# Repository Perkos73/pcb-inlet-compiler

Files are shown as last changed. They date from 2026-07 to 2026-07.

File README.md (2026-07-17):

# PCB INLET

Dwuwarstwowa płytka wejściowa zasilania sieciowego dla projektu Custom Step-Down PSU 230 V → 100 V.

## Stan projektu

Rewizja PCB: `PCB1-PCB-01R1`

Główny plik płytki:

`pcb-inlet.kicad_pcb`

Układ elektryczny, geometria płytki i trasowanie nie zostały zmienione. Ujednolicono nazwę pliku, strukturę repozytorium oraz automatyczne testy GitHub Actions.

## Parametry PCB

| Parametr | Wartość |
|---|---:|
| Wymiary | 105 × 70 mm |
| Liczba warstw miedzi | 2 |
| Materiał | FR-4 |
| Grubość laminatu | 1,6 mm |
| Grubość miedzi | 70 µm / 2 oz |
| Montaż elementów | THT |
| Liczba footprintów | 10 |
| Liczba przelotek | 0 |
| Otwory montażowe | 4 × 3,2 mm, NPTH, M3 |

## Funkcje płytki

Płytka zawiera:

- wejście i wyjście sieciowe na złączach śrubowych,
- bezpiecznik topikowy w przewodzie fazowym,
- warystor zabezpieczający,
- kondensator klasy X2,
- rezystor rozładowujący,
- sieci `L_IN`, `L_FUSED` i `N_IN`,
- cztery otwory montażowe M3.

## Struktura repozytorium

Najważniejsze pliki:

- `pcb-inlet.kicad_pcb` — projekt płytki KiCad,
- `.github/workflows/kicad-validate.yml` — automatyczna kontrola DRC,
- `.github/workflows/kicad-manufacturing.yml` — generowanie plików produkcyjnych,
- `.gitignore` — wykluczenie plików generowanych automatycznie,
- `README.md` — opis projektu.

## Automatyczna walidacja

Workflow `kicad-validate.yml` uruchamia się przy Pull Requestach oraz zmianach na głównej gałęzi.

Walidacja:

1. uruchamia KiCad CLI 8.0.9,
2. otwiera plik PCB,
3. wykonuje pełny raport DRC,
4. wykonuje kontrolę błędów blokujących,
5. zapisuje raporty jako artifact GitHub Actions.

Aktualny wynik kontroli bramkującej:

- 0 błędów,
- 0 niepołączonych padów.

Pełny raport może zawierać ostrzeżenia i naruszenia informacyjne wymagające ręcznej oceny.

## Pliki produkcyjne

Workflow `kicad-manufacturing.yml` jest przeznaczony do automatycznego generowania:

- warstw Gerber,
- plików wierceń,
- map wierceń,
- pliku IPC-D-356,
- raportów DRC,
- manifestu plików,
- sum kontrolnych SHA-256.

Pliki produkcyjne nie są zapisywane bezpośrednio w repozytorium. Są udostępniane w GitHub Actions jako artifact do pobrania.

## Zalecane parametry zamówienia PCB

- 2 warstwy,
- wymiary 105 × 70 mm,
- materiał FR-4,
- grubość 1,6 mm,
- miedź 2 oz,
- solder mask po obu stronach,
- opis po obu stronach,
- bez panelizacji,
- bez kontrolowanej impedancji,
- bez V-score,
- bez metalizacji krawędzi,
- bez otworów castellated.

## Bezpieczeństwo

Projekt pracuje z napięciem sieciowym.

Przed wykonaniem i uruchomieniem płytki należy sprawdzić:

- wymagane odstępy izolacyjne,
- parametry napięciowe i prądowe elementów,
- klasę bezpieczeństwa kondensatora,
- właściwy dobór bezpiecznika,
- sposób uziemienia urządzenia,
- zgodność konstrukcji z obowiązującymi wymaganiami bezpieczeństwa.

Uruchamianie układu powinno odbywać się wyłącznie przez osobę posiadającą odpowiednie doświadczenie z urządzeniami sieciowymi.

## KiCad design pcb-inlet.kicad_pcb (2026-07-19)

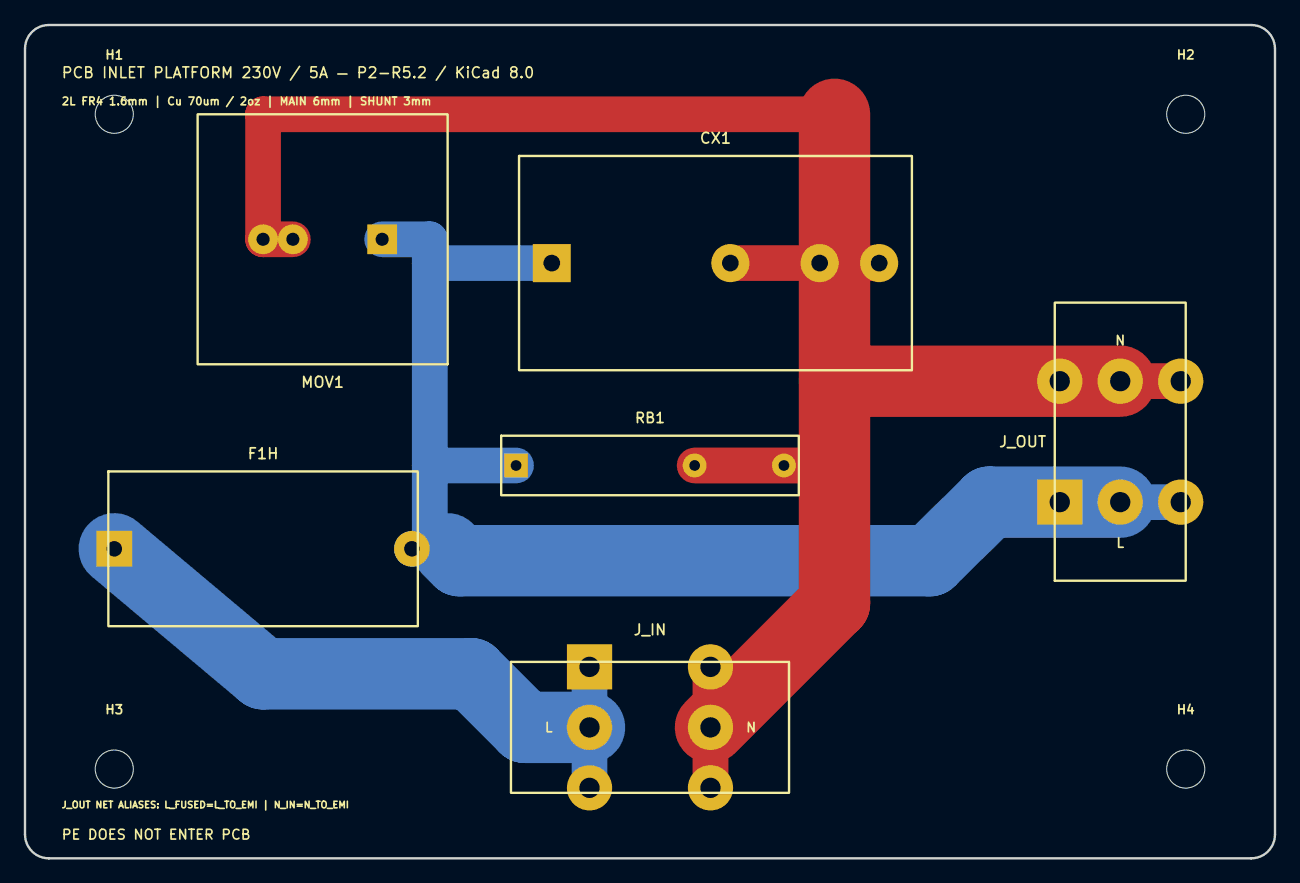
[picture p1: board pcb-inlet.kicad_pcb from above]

Board: 2 copper layers, 105.0 x 70.0 mm, 10 parts (0 on the bottom side), 3 nets.

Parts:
CX1: Iskra KNB1532 0.22uF X2 / fitted P22.5; CX_X2_P15_P22.5_P27.5
F1H: Schurter OGN 0031.8211 / F1 T500mA; Schurter_OGN_0031.8211
H1, H2, H3, H4: NPTH 3.2 / 6mm mains clearance; MountingHole_3.2mm_M3
J_IN: Phoenix 1998784 PCV + plug 1913507; Phoenix_1998784_PCV_2P_P10.16
J_OUT: Phoenix 1998784 PCV + plug 1913507; Phoenix_1998784_PCV_2P_P10.16
MOV1: S14K320 fitted / S20 option; MOV_S14_S20_P7.5_P10
RB1: VR37 680k / fitted P15; VR37_P15_P22.5

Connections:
L_FUSED: CX1.1, F1H.2, J_OUT.1, MOV1.1, RB1.1
L_IN: F1H.1, J_IN.1
N_IN: CX1.2, J_IN.2, J_OUT.2, MOV1.2, RB1.2

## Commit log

2026-07-13 Automatyczny zapis Gerberów [skip ci]
    [pcb_inlet-B_Courtyard.gbr, pcb_inlet-B_Fab.gbr, pcb_inlet-B_Mask.gbs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]
2026-07-16 Update README to match pcb-psu-led standard
2026-07-16 Add KiCad validation and manufacturing workflows
2026-07-16 Rename PCB file for consistent naming
    [pcb-inlet.kicad_pcb]
2026-07-16 Remove obsolete generated Gerber files
    [pcb_inlet-B_Courtyard.gbr, pcb_inlet-B_Fab.gbr, pcb_inlet-B_Mask.gbs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]
2026-07-16 Remove obsolete Gerber workflow
2026-07-17 Use KiCad 8 for PCB validation
2026-07-17 Pass PCB filename into validation container
2026-07-17 Remove unsupported KiCad 8 render commands
2026-07-17 Use KiCad 8 for manufacturing workflow
2026-07-17 Migrate project and workflows to KiCad 10.0.4
    [pcb-inlet.kicad_pcb]
2026-07-19 pcb: set rev P2-R4.1, Lead-Free HASL and add L/N silk
    - title block revision: PCB-INLET_P2-R4.1
    - surface finish: Lead-Free HASL
    - L/N silkscreen labels for J_IN and J_OUT
    - no changes to copper, routing, pads, holes, outline, placement, nets or courtyard
    [pcb-inlet.kicad_pcb]
2026-07-19 set REVISION to PCB-INLET_P2-R4.1g.yml
    Align production folder, MANIFEST, ZIP and artifact name with the board
    title_block revision (PCB-INLET_P2-R4.1). Single env value change; no
    change to KiCad version, DRC, export commands or the .kicad_pcb.
